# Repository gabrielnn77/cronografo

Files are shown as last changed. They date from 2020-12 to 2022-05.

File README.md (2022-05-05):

# cronógrafo
cronógrafo para aire comprimido basado en Arduino

# Listado de materiales para la construccion
* Arduino uno (compatible) . Verificar que tenga cristal para los timer <link>https://articulo.mercadolibre.com.ar/MLA-802733629-arduino-uno-r3-cable-usb-atmega328p-smd-compatible-ch340-_JM</link>
* shield LCD 16x2 con botones <link>https://articulo.mercadolibre.com.ar/MLA-861304422-shield-display-lcd-1602-16x2-botones-arduino-_JM</link>
* 2 fotodiodos. Yo use estos : osram Sfh 203 Fa <link>https://articulo.mercadolibre.com.ar/MLA-698467492-sfh-203-fa-fotodiodo-receptor-infrarrojo-900nm-itytarg-_JM</link> . Los baratos no funcionan.
* 2 Leds infrarojos. Use unos baratos de 850 o 900 nm
* 4 resistencias para adecuar las tensiones de los diodos emisores y reeptores. Ver valores y recomendaciones en los comentarios del código fuente.
* soporte para los sensores y caja para el Arduino. Impreso en 3D con resina PLA (puede ser una mejor, pero esta funciona)
* Alguna forma de alimentar el Arduino. Yo use un powerBank de esos para celulares (la contra es que para apagarlo hay que desenchufarlo, y queda fuera de la caja del arduino, con un cable usb de impresora), pero vienen modulos para arduino que usan una pila 18650 que se pueden montar dentro de la caja, y agregarle un switch de encendido, y hasta tienen una entrada microUSB para cargar la pila sin sacarla de la caja, con un cargador de celulares (tener en cuenta que hay que modificar la caja para darle lugar para el modulo de batería) <link>https://articulo.mercadolibre.com.ar/MLA-878152686-modulo-power-bank-para-1-bateria-18650-5v-3v-micro-usb-_JM</link>

# caracteristicas y limitaciones
* Es un cronógrafo de tubo, solo para aire comprimido. Por la forma de acoplarlo al caño, creo que seria incómo para rifles con miras abiertas. Se adapta bien a caños que van desde los 15 mm a los 40 mm (aprox). Para acoplarlo al caño, usé un par de cordones elásticos con esas trabas que se usan en ropa deportiva, capuchas de camperas, impermeables para lluvia, etc. Se puede usar una cinta con abrojo también, pero el elástico me pareció mas práctico para colocarlo.
* Mide la velocidad en FPS y m/s
* Mide hasta 150 velocidades (se puede cambiar en el firmware este valor, no lo crei necesario)
* Muestra velocidad Máx (con el nro de disparo), Mín (con el nro de disparo), Promedio (con la cantidad de disparos que usó para calcular el promedio), y spread de la totalidad de los disparos registrados.
* Muestra la energía en Joules. Por defecto lo calcula utilizando un peso de balín de 18 grains, pero se puede cambiar el peso desde los botones, y recalcula la energía de cada disparo
* Para verificar el funcionamiento, se compararon las mediciones en simultáneo con un cronógrafo comercial marca Chrony modelo alpha (rojo), dando diferencias de +- 6 FPS . Creo que es factible mejorar la presición por dos caminos (pero no lo probé): eliminar el código que en el loop principal llama a la función que lee los botones (hace una lectura analógica del pin A0, para determinar que boton se presionó, creo que eso podría generar variaciones en el tiempo para atender la interrupciones disparadas por los sensores), dejando que solamente se muestre la velocidad del último disparo, y la otra forma de mejorar la presición , sería aumentar la distancia entre sensores, actualmente está en 10 cm, con llevarlo a 20 cm se mejoraría la presición en la toma del tiempo.

# uso de los botones
* por defecto, la pantalla muestra la velocidad del ultimo disparo. Con los botones UP y DOWN se visualizan los disparon anteriores y posteriores. Con los botones LEFT y RIGHT se va cambiando los modos de visualizacion: VELOCIDAD - vel MAX - vel MIN - vel PROMEDIO - SPREAD - PESO del balín (para el cálculo de energía) - DESHABILITAR teclado (lo usé para probar si deshabilitando la lectura de los botones daba lecturas de velocidad diferentes, pero no noté diferencia).
* si esta en modo PESO, las teclas UP y DOWN modifican el peso del balín, lo que cambia el cálculo de energía en joules.
* si esta en modo DESHABILITAR, y se presiona la tecla SELECT, se deshabilita el teclado
* en cualquier otro modo, la tecla SELECT vuelve al modo VELOCIDAD
* el teclado ademas dispone de una tecla RESET que reinicia la placa arduino
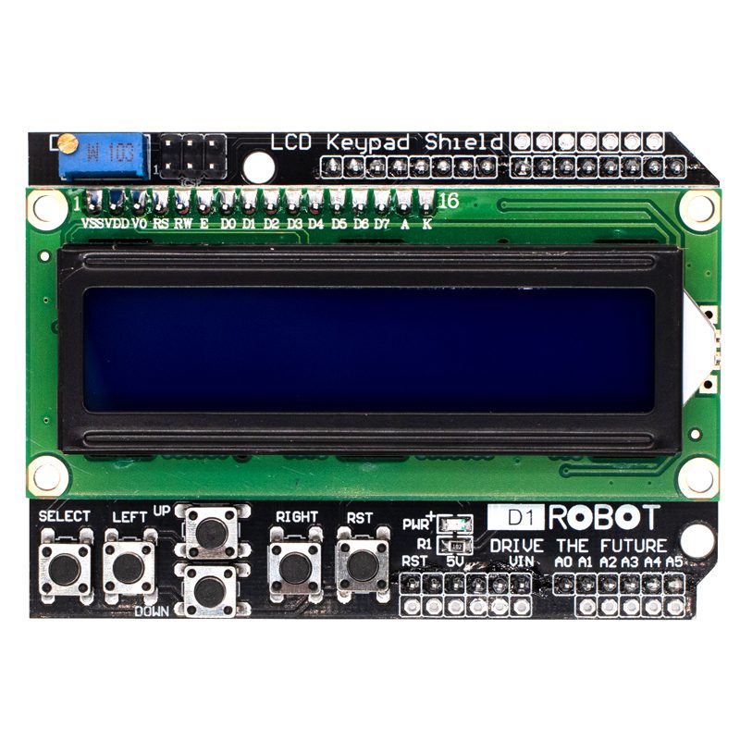
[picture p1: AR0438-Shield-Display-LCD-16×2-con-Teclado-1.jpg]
* 

# software o herramientas necesarias
* aplicacion fritzing para visualizar el diagrama de conexión, o algun visor de imágenes porque lo exporté a PNG
* IDE de arduino para subir el codigo a la placa
* freecad para ver o modificar el diseño de los soportes, y exportarlos a STL para imprimirlos en 3d

# pruebas, fotos y videos
* Simulacion 3d del soporte y caja: <link>https://youtu.be/3Tz094T5HoM</link>
* Prueba inicial contra un chrony, con el codigo actual la diferencia de FPS es mas chica(+-5FPS): <link>https://youtu.be/s2DOzHH34lQ</link>
* los videos anteriores estan hechos para el soporte anterior, pero no encajaba del todo bien la placa adentro de la caja, ademas al estar al costado, queda desequilibrado, recomiendo usar el soporte_2 que esta mas ajustado al tamaño del arduino y el shield de la pantalla

# nuevo diseño del soporte
* la separacion entre sensores sera de 129 mm
* el largo total sera de 230 mm
* en breve subo los nuevos diseños, quiero mandarlos a imprimir primero, por si hay que modificar algo
* con este nuevo diseño, hay que cambiar en el codigo del arduino la constante que define la separacion de los sensores, creo que de esta forma va a ser mas precisa la medicion, porque en el rango 830 - 1100 FPS no va a caer dentro del tiempo de un desborde del contador

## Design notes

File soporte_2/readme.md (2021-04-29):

Este soporte mejora como se encastra el arduino dentro de la caja, y el display queda de frente sobre el caño.
Aunque puede interferir con la mira, asi queda mas equilibrado y no se cae para un costado por el peso de la caja
Los archivos STL son los que se usan para la impresion 3D, los otros, son los archivos fuente, para editarlos con freeCAD
en breve subo los archivos corregidos

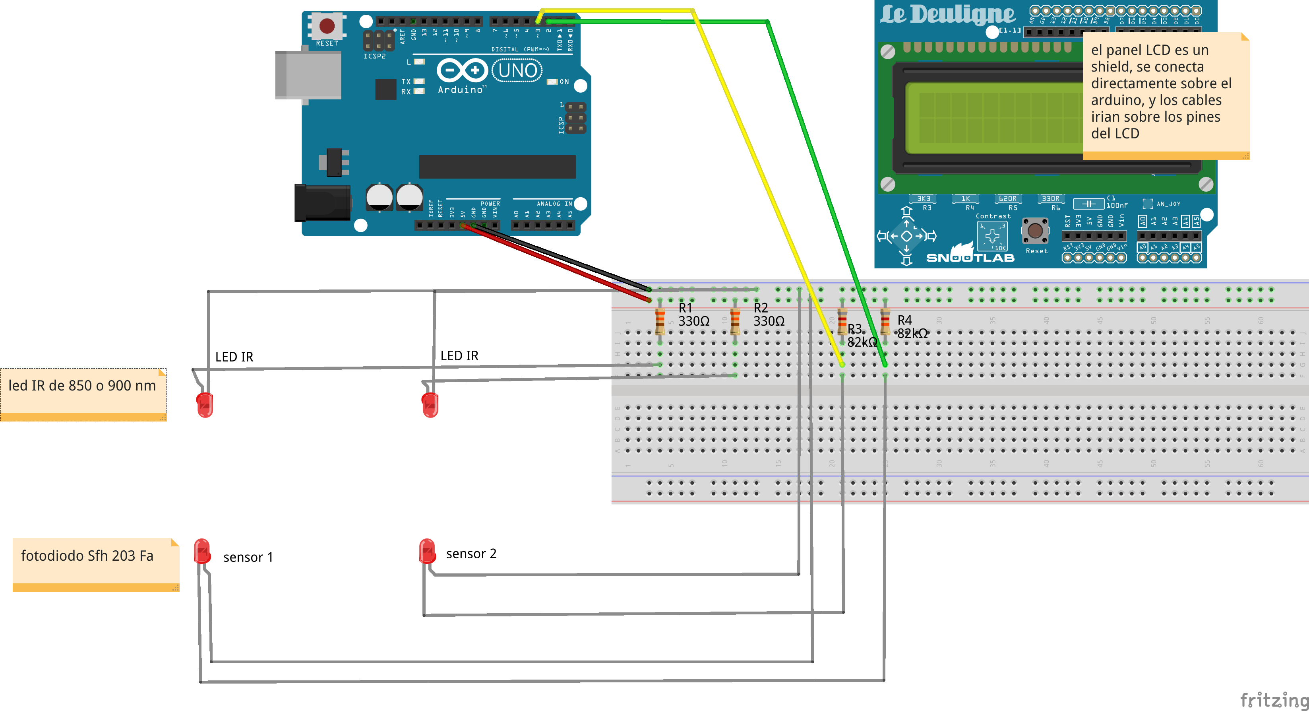
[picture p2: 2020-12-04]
cronografo_bb.png

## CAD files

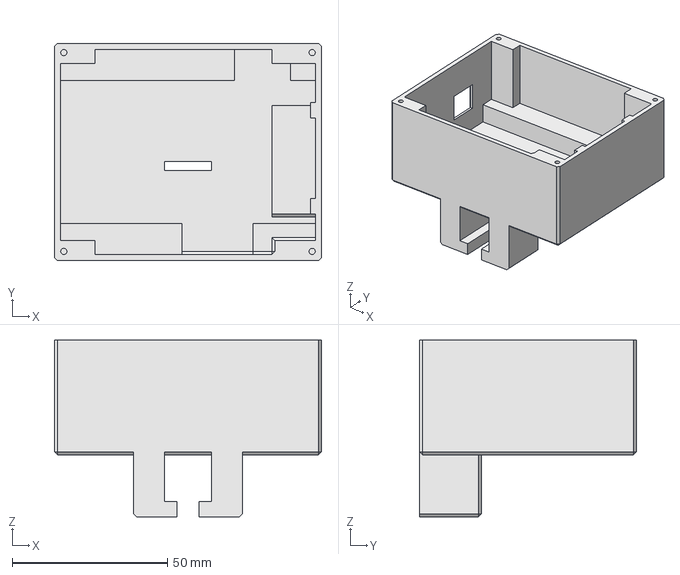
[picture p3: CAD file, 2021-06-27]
soporte_2/caja_base_01.FCStd
86.0 x 70.0 x 57.0 mm

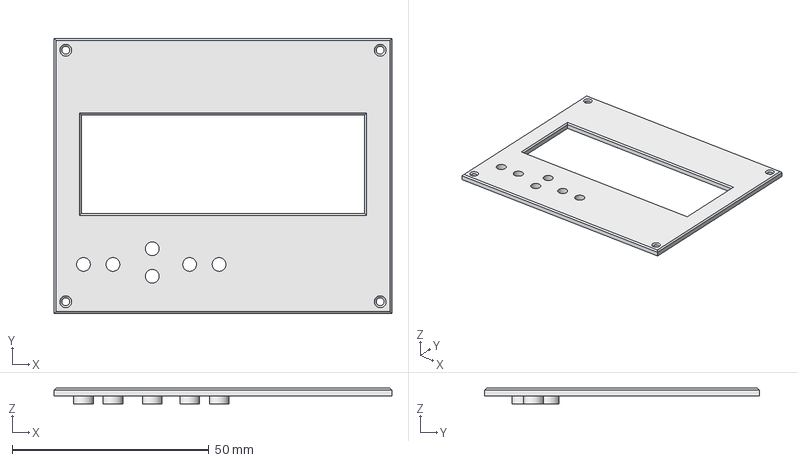
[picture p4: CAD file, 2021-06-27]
soporte_2/caja_tapa_01.FCStd
86.0 x 70.0 x 4.00 mm

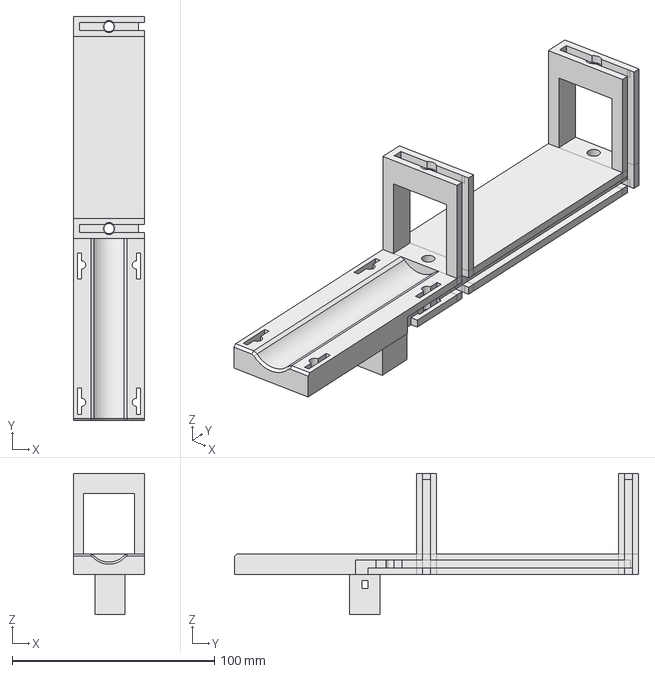
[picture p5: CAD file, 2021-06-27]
soporte_2/montaje_02.FCStd
35.0 x 200.0 x 70.0 mm

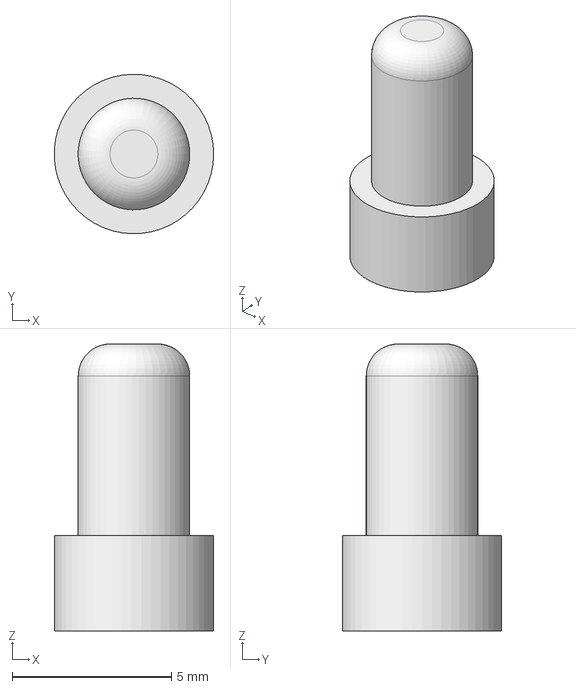
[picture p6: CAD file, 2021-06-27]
soporte_2/caja_boton_01.FCStd
5.00 x 5.00 x 9.00 mm

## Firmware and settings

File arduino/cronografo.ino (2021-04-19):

/*
 * version : 0.9
 *    corregidos errores en el display y mas documentacion sobre las resistencias
 * version : 0.8
 *    agregada opcion en el menu para desabilitar los botones
 *    esto es para probar si las lecturas son mas consistentes, porque
 *    me estaba dando un diferencia con el chrony alpha de +-5FPS
 * 
 * version : 0.7
 *    mejorada la consistencia entre lecturas, se deshabilitan timer0 y timer1 desde la 
 *    lectura del primer sensor, y se vuelven a habilitar despues de la lectura del segundo
 *    los necesita a los dos timer, porque el timer0 lo usa para funciones delay en la lectura 
 *    de los botones, y el timer1 lo usa para la iluminacion del display
 * 
 para el LED IR : emisor
    330 ohms - 180 ohms 
                en algunos LED IR con 330 no tiene potencia para exitar el receptor
                  - los LED IR que compre en zafaronni no anduvieron, les tenia que poner un resistencia
                  de 50 ohms para que anden, pero calientan demasiado, se va a quemar
                  - los que compre el 2021-04-10 en radiofuturo andan con resistencias de 180 ohms
                  los anteriores (mas claritos) andan con 320 ohms
                supuestamente tienen que ser de 850-900 nanometros, pero como son genericos
                los vendedores ni saben de cuanto son
                
 fotodiodo : receptor o sensor (PULLUP: da un 0 cuando ve luz, y cuando cortas el az da un 1
    82k ohms 
    gnd<-------[fotodiodo]----|-------[resistencia]------5V
                              |
                              |
                            pin digital
             el que anduvo es uno marca osram Sfh 203 Fa (los genericos no van)
             

                            
https://www.luisllamas.es/leer-un-pulsador-con-arduino/
https://hardwarehackingmx.wordpress.com/2014/01/15/leccion-20-arduino-sensor-infrarrojo-basico/


conexion emisor y receptor

  Emisor - LED IR
      (------- +   (pata larga a voltaje)
      (____    -   (pata corta a masa , negativo , marca plana , cuerpo grande dentro del led)

  Receptor - fototransistor
      (----      +   (este es el colector: C tiene una marca plana o corte flat y es mas corto )
      (_________ -    ( pata larga a masa )




https://wiki.dfrobot.com/Arduino_LCD_KeyPad_Shield__SKU__DFR0009_
  pantalla LCD - shield
   usa el A0 para control de botones


   
FOTODIODO Sfh 203 Fa // Sfh203 Fa Osram

conexion, resistencia
      este parece mejor:
      https://www.i-ciencias.com/pregunta/48286/como-utilizar-sfh235-ir-fotodiodo-correctamente



      IMPLEMENTACION UTILIZANDO LOS REGISTROS DEL TIMER DE ARDUINO
      PARA OBRTENER MEJOR RESOLUCION DEL TIEMPO

      con la funcion micros() se tiene una resolucion de 4us , que da un error de 8.5 FPS para lecturas de alrededor de 900 FPS

      https://stackoverflow.com/questions/36254652/arduino-tcnt1-to-count-clock-cycles-between-interrupts
      int t1;// declare global variable somewhere
      t1 = TCNT1; //save timer value in ISRx interrupts
      Be sure to setup prescaler value TCCR1B.CSn and handle timer overflow interrupt, else you will lose time data: ISR(TIMER1_OVF_vect)

      https://www.instructables.com/Arduino-Timer-Interrupts/

      voy a usar:
      timer1 : 16 bits :: NO LO USO PORQUE ME DA CONFLICTO CON EL LCD
      prescaler: 8 (2 MHz, deberia ser 0.5 us de resolucion) (1 us de diferencia da 2 FPS de error a 900 FPS)

      timer2 : 8 bits 
      prescaler: 1 (16 MHz, deberia ser [0.0000000625 s] - [0.0625 us] de resolucion)
        ---> era medio inestable, daba lecturas raras


      timer2
        prescaler : 8  --> 0.5 us
        modo interrupcion en overflow
        tomado de https://github.com/ElectricRCAircraftGuy/eRCaGuy_TimerCounter
      

      DESHABILITAR timer0
      no se puede usar delay(), millis() o micros()
      https://forum.arduino.cc/index.php?topic=206513.0
      https://forum.arduino.cc/index.php?topic=200992.0

*/

#include <CheapLCD.h>

CheapLCD lcd;

// --------------------------------------------------------------------------------------
// define some values used by the panel and buttons
int lcd_key     = 0;

#define btnRIGHT  0
#define btnUP     1
#define btnDOWN   2
#define btnLEFT   3
#define btnSELECT 4
#define btnNONE   5
// --------------------------------------------------------------------------------------

// --------------------------------------------------------------------------------------
// constantes y variables GLOBALES relacionadas al chrony
//  sensor 1 : D2
#define pinS1     2
//  sensor 2 : D3
#define pinS2     3
//  tiempo para ignorar rebotes en las lecturas de los sensores
#define rebote    1000000
//  10 cm expresado en pie : distancia entre sensores
#define long_pie  0.328084
//  10 cm expresado en [m] : distancia entre sensores
#define long_m  0.1

// velocidad minima permitida
#define vel_min 1
// velocidad maxima permitida
#define vel_max 5000

// muestra velocidad del disparo
#define modoVEL     0
// muestra velocidad MAX
#define modoMAX     1
// muestra velocidad MIN
#define modoMIN     2
// muestra velocidad AVG
#define modoAVG     3
// muestra SPREAD
#define modoSPREAD  4
// muestra peso balin
#define modoPESO    5
// deshabilita los botones
#define modoDISABLE    6
// es el maximo valor de modo definido, es para manejar los botones y el cambio de modo
#define modoTOPE 6

//  es el tamaño del buffer para alamacenar mediciones
#define CANT_DISPAROS 200

  volatile unsigned long desborde = 0;
  volatile unsigned char running = 0;
  volatile unsigned long tiempos[CANT_DISPAROS];
  volatile unsigned char idx = 0;       //  indice de la lectura en el arreglo
  volatile unsigned long tiempo_actual = 0;
  volatile boolean flag_save;

  byte TCCR0A_old;
  byte TCCR0B_old;
  byte TCCR1A_old;
  byte TCCR1B_old;
  
  byte idx_avg = 0;            //  cantidad de lecturas validas, para sacar el promedio
  byte idx_ant = 0;            //  indice lectura anterior, para detectar nuevas lecturas
  byte idx_show = 0;           //  indice lectura mostrada en el LCD
  byte idx_min = 0;            //  el indice del disparo a MIN vel
  byte idx_max = 0;            //  el indice del disparo a MAX vel
  byte show_mode = modoVEL;    //  define el tipo de dato mostrado en el LCD
  boolean enable_keys = true;  // define si esta habilitada la lectura de los botones
  volatile byte count_err = 0;

  long peso_balin = 18;        // peso en gr, sin decimales


  

  long maxFPS = 0;   //  maxima
  long minFPS = 0;   //  minima
  long avgFPS = 0;   //  promedio
  long currFPS = 0;  //  actual

// --------------------------------------------------------------------------------------




// --------------------------------------------------------------------------------------

// --------------------------------------------------------------------------------------



// --------------------------------------------------------------------------------------
void setup() {

  unsigned long aux1;
  
//Serial.begin(9600);

  pinMode(pinS1, INPUT);
  pinMode(pinS2, INPUT);

  

  //  inicializo los arrreglos con 0 para descartar falsas lecturas
  for(unsigned char i = 0 ; i < CANT_DISPAROS ; i++){
    tiempos[i] = 0;
  }
  //  accedo a cada elemento del array, porque sino parece que no lo inicializa
  // parece alguna optimizacion del compilador o algo asi
  for(unsigned char i = 0 ; i < CANT_DISPAROS ; i++){
    aux1 += tiempos[i] ;
  }

  // INDICAMOS QUE TENEMOS CONECTADA UNA PANTALLA DE 16X2
  lcd.begin();
  lcd.backlightOff();
  lcd.backlightLevel(35);
  lcd.backlightOn();
  // MOVER EL CURSOR A LA PRIMERA POSICION DE LA PANTALLA (0, 0) Y BORRAR
  lcd.clear();
  // IMPRIMIR EN LA PRIMERA LINEA
  lcd.print("GC Chrony");
  // MOVER EL CURSOR A LA SEGUNDA LINEA (1) PRIMERA COLUMNA (0)
  lcd.setCursor ( 0, 1 );
  // IMPRIMIR OTRA CADENA EN ESTA POSICION
  lcd.print(" -- Listo -- ");


///  Serial.println("setup listo!");
///  Serial.println("------------------------------------------");

  show_mode = modoVEL;
  idx_show = 0;
  enable_keys = true;
  count_err = 0;


    //  preparo el timer2
    noInterrupts();//stop interrupts
    TCCR2A = 0;// set entire TCCR2A register to 0
    TCCR2B = 0;// same for TCCR2B
    TCNT2  = 0;//initialize counter value to 0
    
    //Enable Timer2 overflow interrupt; see datasheet pg. 159-160
    TIMSK2 |= 0b00000001; //enable Timer2 overflow interrupt. (by making the right-most bit in TIMSK2 a 1)

    //set timer2 to "normal" operation mode.  See datasheet pg. 147, 155, & 157-158 (incl. Table 18-8).  
    //-This is important so that the timer2 counter, TCNT2, counts only UP and not also down.
    //-To do this we must make WGM22, WGM21, & WGM20, within TCCR2A & TCCR2B, all have values of 0.
    TCCR2A &= 0b11111100; //set WGM21 & WGM20 to 0 (see datasheet pg. 155).
    TCCR2B &= 0b11110111; //set WGM22 to 0 (see pg. 158).

    desborde = 0;

    //  deshabilito timer0 y timer1
    //  tiene conflictos con LCD
    //TCCR0A = 0;
    //TCCR0B = 0;
    TCCR0A_old = TCCR0A;
    TCCR0B_old = TCCR0B;
    TCCR1A_old = TCCR1A;
    TCCR1B_old = TCCR1B;
    
    interrupts();//allow interrupts
  

  //  interrupciones
  attachInterrupt(digitalPinToInterrupt(pinS1), sensor1, RISING);
  attachInterrupt(digitalPinToInterrupt(pinS2), sensor2, RISING);



  /// datos para testear: de 200 a 168 m/s
/*
  for(int i = 0 ; i < 10; i++){
    idx = i;
    tiempos[idx] = (int) (1000 + (3*i*i) );
  }
*/

    //  la primer lectura me da muy lenta, cada ves que reseteo el arduino me pasa eso
    //  pruebo lanzar la interrupcion 1 para ver si 
    //  asi se inicializa todo mejor y queda "atento"
  delay(300);
  sensor1();
  
    
}
// --------------------------------------------------------------------------------------


// --------------------------------------------------------------------------------------
void loop() {


   if(idx_ant < idx){
    //  actualizo los datos agregados, porque hay una lectura nueva
    calcular_datos_FPS(minFPS, maxFPS, avgFPS, currFPS, idx_ant);
    
    // @todo
    //  mostrar datos actualizados
    idx_show = idx_ant;
    show_mode = modoVEL;
    drawLCD(show_mode, idx_show);
//Serial.print("drawLCD("); Serial.print(show_mode); Serial.print(" , "); Serial.print(idx_show); Serial.print(")     // "); Serial.println(__LINE__);

    idx_ant++;
  }

  if(enable_keys){
//Serial.print("PREVIO drawLCD : enable_keys: ["); Serial.print(enable_keys); Serial.print("]     // "); Serial.println(__LINE__);
    lcd_key = read_LCD_buttons();
    if(lcd_key != btnNONE){
      button_to_mode(lcd_key);
      if(enable_keys) drawLCD(show_mode, idx_show);
//Serial.print("drawLCD("); Serial.print(show_mode); Serial.print(" , "); Serial.print(idx_show); Serial.print(")     // "); Serial.println(__LINE__);
      delay(300);
    }
  }
  

  //  evitar si se perdio la lectura de sensor 2, que quede esperando para siempre
  if(desborde > 10000){
//    Serial.print("deborde!: "); Serial.println(desborde);
    //resetear contadores
    //  paro el timer1
    //TCCR2B &= ~(1 << CS20);    //  prescaler : 1
    TCCR2B &= ~(1 << CS21);    //  prescaler : 8
    TCNT2 = 0;
    desborde = 0;
    running = 0;
    TCCR0A = TCCR0A_old;
    TCCR0B = TCCR0B_old;
    TCCR1A = TCCR1A_old;
    TCCR1B = TCCR1B_old;
  }

//  si son 3 errores CONSECUTIVOS o mas, habilito de nuevo el teclado
  if(count_err > 2){
    enable_keys = true;
    count_err = 0;
  }
    
//-----------------------------------------------------------
/*
   Serial.print("sensor 1 :  ");
   Serial.print(digitalRead(pinS1));
   Serial.print("    -    sensor 2 :  ");
   Serial.println(digitalRead(pinS2));
   //delay(400);
   */
//-----------------------------------------------------------

}
// --------------------------------------------------------------------------------------


// --------------------------------------------------------------------------------------
// interrupcion cuando llega al desborde del timer
ISR(TIMER2_OVF_vect){
  desborde++;
  
}
// --------------------------------------------------------------------------------------
void sensor1(){

  
  noInterrupts();
  
  //TCCR2B = (1 << CS20);     //  prescaler : 1
  TCCR2B |= (1 << CS21);    //  prescaler : 8
  
  running = ! running;

  //  deshabilito timer0 y timer1
  TCCR0A = 0;
  TCCR0B = 0;
  TCCR1A = 0;
  TCCR1B = 0;
   
  interrupts();
}
// --------------------------------------------------------------------------------------
void sensor2(){


//cli();//stop interrupts
  noInterrupts();
  
  tiempo_actual = TCNT2;
  flag_save = bitRead(TIFR2,0); //grab the timer2 overflow flag value; see datasheet pg. 160
  if (flag_save) { //if the overflow flag is set
    //update variable just saved since the overflow flag could have just tripped between previously saving the TCNT2 value and reading bit 0 of TIFR2.  
    //If this is the case, TCNT2 might have just changed from 255 to 0, and so we need to grab the new value of TCNT2 to prevent an error of up 
    //to 127.5us in any time obtained using the T2 counter (ex: T2_micros). (Note: 255 counts / 2 counts/us = 127.5us)
    tiempo_actual = TCNT2;
    desborde++; //force the overflow count to increment
    TIFR2 |= 0b00000001; //reset Timer2 overflow flag since we just manually incremented above; see datasheet pg. 160; this prevents execution of Timer2's overflow ISR
  }
  tiempo_actual += (desborde * 256);
  
  
  //  paro el timer1
  //TCCR2B &= ~(1 << CS20);    //  prescaler : 1
  TCCR2B &= ~(1 << CS21);    //  prescaler : 8

  //  dejo el timer0 como estaba y timer1 tambien!
  TCCR0A = TCCR0A_old;
  TCCR0B = TCCR0B_old;
  TCCR1A = TCCR1A_old;
  TCCR1B = TCCR1B_old;
  
  interrupts();
//sei();//allow interrupts
  


  //  registro todo y reseteo contadores
  if(running){
    tiempos[idx] = tiempo_actual;
    count_err = 0;
  }
  else{
    //  error de lectura, no estaba corriendo el reloj
    tiempos[idx] = 0;
    if(count_err < 10) count_err++;
  }

  //  controlo de no desbordar el buffer de lecturas
  if(idx < (CANT_DISPAROS - 1)) idx++;
  TCNT2 = 0;
  desborde = 0;
  running = 0;
  
  
  

}
// --------------------------------------------------------------------------------------





// --------------------------------------------------------------------------------------
//  dibuja la pantalla LCD, dependiendo del tipo de informacion a mostrar
void drawLCD(unsigned char modo, unsigned char idx_info){


//Serial.print(" MODO: "); Serial.println(modo);

  switch (modo)               // depending on which button was pushed, we perform an action
 {
   case modoVEL:
     {
        drawLCD_VEL(idx_info);
        break;
     }
   case modoMAX:
     {
        drawLCD_MAX(idx_info);
        break;
     }
   case modoMIN:
     {
        drawLCD_MIN(idx_info);
        break;
     }
   case modoAVG:
     {
        drawLCD_AVG(idx_info);
        break;
     }
   case modoSPREAD:
     {
        drawLCD_SPREAD(idx_info);
        break;
     }
   case modoPESO:
     {
        drawLCD_PESO(idx_info);
        break;
     }
   case modoDISABLE:
      {
        drawLCD_DISABLE(idx_info);
        break;
      }
 }
  
}
// --------------------------------------------------------------------------------------

// --------------------------------------------------------------------------------------
void drawLCD_VEL(unsigned char idx_info){

  long vel;
///Serial.println(" drawLCD_VEL ");
  
  lcd.clear();

  //  linea 1
  lcd.setCursor(0,0);
  lcd.print("N#| FPS|M/S|Joul");

  //  linea 2
  lcd.setCursor(0,1);
  if(idx_info < 9){
    lcd.print(" ");
  }
  lcd.print(idx_info+1);
  lcd.print("|");
  
  vel = getVel_FPS(idx_info);
  if((vel < vel_min) || (vel > vel_max)){
    lcd.print("ERRO");
  }
  else{
    //  FPS
    if(vel < 1000){
      lcd.print(" ");
    }
    if(vel < 100){
      lcd.print(" ");
    }
    if(vel < 10){
      lcd.print(" ");
    }
    lcd.print(vel);

    // M/S
    vel = FPS_to_MS(vel);
    lcd.print("|");
    if(vel < 100){
      lcd.print(" ");
    }
    if(vel < 10){
      lcd.print(" ");
    }
    lcd.print(vel);
    
    //  joules
    lcd.print("|");
    double pot;
    pot = (double)((vel * vel * peso_balin) / 30865.0);
    if(pot < 99.9) lcd.print(pot, 1);
    else lcd.print(pot, 0);
/*
Serial.print(" vel: "); Serial.print(vel);
Serial.print("  pot: "); Serial.print(pot);
Serial.print("  peso: "); Serial.print(peso_balin);
Serial.println("");
*/
  }
  
}
// --------------------------------------------------------------------------------------

// --------------------------------------------------------------------------------------
void drawLCD_MAX(unsigned char idx_info){

   int vel;
//Serial.println(" drawLCD_MAX ");

  lcd.clear();

  //  linea 1
  lcd.setCursor(0,0);
  lcd.print("MAX | FPS  | M/S");

  //  linea 2
  lcd.setCursor(0,1);
  if(idx_max < 9){
    lcd.print("  ");
  }
  else if(idx_max < 99){
    lcd.print(" ");
  }

  lcd.print(idx_max+1);
  lcd.print(" | ");

  vel = maxFPS;
  if(vel < 1000){
    lcd.print(" ");
  }
  if(vel < 100){
    lcd.print(" ");
  }
  if(vel < 10){
    lcd.print(" ");
  }
  lcd.print(vel);

  vel = FPS_to_MS(vel);
  lcd.print(" | ");
  if(vel < 100){
    lcd.print(" ");
  }
  if(vel < 10){
    lcd.print(" ");
  }
  lcd.print(vel);
  
}
// --------------------------------------------------------------------------------------

// --------------------------------------------------------------------------------------
void drawLCD_MIN(unsigned char idx_info){

  int vel;
  
//Serial.println(" drawLCD_MIN ");

  lcd.clear();

  //  linea 1
  lcd.setCursor(0,0);
  lcd.print("MIN | FPS  | M/S");

  //  linea 2
  lcd.setCursor(0,1);
  if(idx_min < 9){
    lcd.print("  ");
  }
  else if(idx_min < 99){
    lcd.print(" ");
  }

  lcd.print(idx_min+1);
  lcd.print(" | ");

  vel = minFPS;
  if(vel < 1000){
    lcd.print(" ");
  }
  if(vel < 100){
    lcd.print(" ");
  }
  if(vel < 10){
    lcd.print(" ");
  }
  lcd.print(vel);

  vel = FPS_to_MS(vel);
  lcd.print(" | ");
  if(vel < 100){
    lcd.print(" ");
  }
  if(vel < 10){
    lcd.print(" ");
  }
  lcd.print(vel);
  
}
// --------------------------------------------------------------------------------------

// --------------------------------------------------------------------------------------
void drawLCD_AVG(unsigned char idx_info){

  int vel;
//Serial.println(" drawLCD_AVG ");

  lcd.clear();

  //  linea 1
  lcd.setCursor(0,0);
  lcd.print("AVG | FPS  | M/S");

  //  linea 2
  lcd.setCursor(0,1);
  if(idx_avg < 10){
    lcd.print("  ");
  }
  else if(idx_avg < 100){
    lcd.print(" ");
  }

  lcd.print(idx_avg);
  lcd.print(" | ");

  vel = avgFPS;
  if(vel < 1000){
    lcd.print(" ");
  }
  if(vel < 100){
    lcd.print(" ");
  }
  if(vel < 10){
    lcd.print(" ");
  }
  lcd.print(vel);

  vel = FPS_to_MS(vel);
  lcd.print(" | ");
  if(vel < 100){
    lcd.print(" ");
  }
  if(vel < 10){
    lcd.print(" ");
  }
  lcd.print(vel);
  
}
// --------------------------------------------------------------------------------------

// --------------------------------------------------------------------------------------
void drawLCD_SPREAD(unsigned char idx_info){

  int vel;
///Serial.println(" drawLCD_SPREAD ");

  lcd.clear();

  //  linea 1
  lcd.setCursor(0,0);
  lcd.print("SPRE| FPS  | M/S");

  //  linea 2
  lcd.setCursor(0,1);
  if(idx_avg < 10){
    lcd.print("  ");
  }
  else if(idx_avg < 100){
    lcd.print(" ");
  }

  lcd.print(idx_avg);
  lcd.print(" | ");

  vel = maxFPS - minFPS;
  if(vel < 1000){
    lcd.print(" ");
  }
  if(vel < 100){
    lcd.print(" ");
  }
  if(vel < 10){
    lcd.print(" ");
  }
  lcd.print(vel);

  vel = FPS_to_MS(vel);
  lcd.print(" | ");
  if(vel < 100){
    lcd.print(" ");
  }
  if(vel < 10){
    lcd.print(" ");
  }
  lcd.print(vel);
}
// --------------------------------------------------------------------------------------

// --------------------------------------------------------------------------------------
void drawLCD_PESO(unsigned char idx_info){

  int vel;
///Serial.println(" drawLCD_PESO ");

  lcd.clear();

  //  linea 1
  lcd.setCursor(0,0);
  lcd.print("Shot| Gr | Joule");

  //  linea 2
  lcd.setCursor(0,1);
  if(idx_info < 9){
    lcd.print("  ");
  }
  else if(idx_info < 99){
    lcd.print(" ");
  }

  lcd.print(idx_info+1);
  lcd.print(" |");

  if(peso_balin < 100.0){
    lcd.print(" ");
  }
  if(peso_balin < 10.0){
    lcd.print(" ");
  }
  lcd.print(peso_balin);
  lcd.print(" |  ");

  vel = getVel_FPS(idx_info);
  vel = FPS_to_MS(vel);
  
  float pot;
  pot = (float) ((vel * vel * peso_balin) / 30865.0);
  lcd.print(pot, 1);
}
// --------------------------------------------------------------------------------------

// --------------------------------------------------------------------------------------
void drawLCD_DISABLE(unsigned char idx_info){

///Serial.println(" drawLCD_DISABLE ");

  lcd.clear();

  //  linea 1
  lcd.setCursor(0,0);
  lcd.print("Bloquear");

  //  linea 2
  lcd.setCursor(0,1);
  lcd.print(" teclado?");

}
// --------------------------------------------------------------------------------------
void drawLCD_DISABLED(){

//Serial.println(" drawLCD_DISABLED ");
//Serial.print(" enable_keys : ");Serial.println(enable_keys);
  lcd.clear();

  //  linea 1
  lcd.setCursor(0,0);
  lcd.print("Teclado");

  //  linea 2
  lcd.setCursor(0,1);
  lcd.print(" Bloqueado");

}
// --------------------------------------------------------------------------------------
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

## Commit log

2020-12-04 Update cronografo.ino
    mejore la documentacion un poquito
2020-12-04 Add files via upload
    diagrama de conexion
    [cronografo.fzz]
2020-12-08 Update cronografo.ino
    agregada opción para deshabilitar los botones, para probar si se puede disminuir el jitter (variación) en las mediciones (que es de +-5FPS)
    [cronografo.ino]
2020-12-11 Update cronografo.ino
    si hay 3 lecturas en sensor 2 (sin pasar por sensor 1) consecutivas, vuelvo a habilitar los botones
2021-04-19 Update cronografo.ino
    mas documentacion sobre las resistencias usadas en los LED y un fix en el display que mostraba corridos los caracteres
    [cronografo.ino]
2021-06-27 Add files via upload
    se mejora el encastre de la placa dentro de la caja
    [caja_base_01.FCStd, caja_boton_01.FCStd, caja_tapa_01.FCStd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]
